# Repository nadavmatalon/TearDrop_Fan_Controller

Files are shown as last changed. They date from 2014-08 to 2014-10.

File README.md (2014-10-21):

#TearDrop Fan Controller

##Table of Contents

* [Screenshots](#screenshots)
* [About the Project](#about-the-project)
* [About the Fan Controller](#about-the-fan-controller)
* [License](#license)

##Screenshots

<table>
	<tr>
		<td align="center" width=25% >
			<a href="https://raw.githubusercontent.com/nadavmatalon/TearDrop_Fan_Controller/master/images/TDFC_Arduino.jpg">
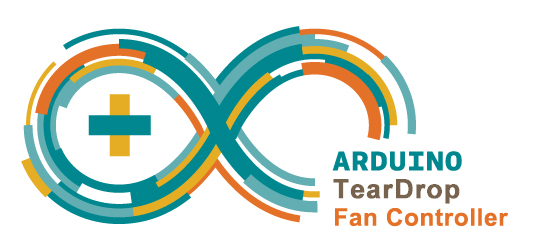
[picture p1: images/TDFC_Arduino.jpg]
				
			</a>
		</td>
		<td align="center" width=25% >
			<a href="https://raw.githubusercontent.com/nadavmatalon/TearDrop_Fan_Controller/master/images/TDFC_PCB.jpg">
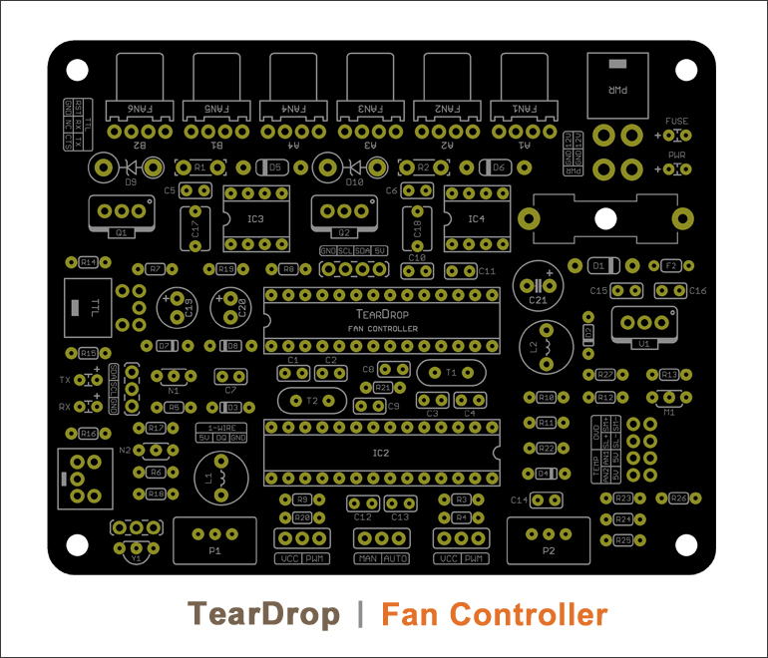
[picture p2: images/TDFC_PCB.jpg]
				
			</a>
		</td>
		<td align="center" width=25% >
			<a href="https://raw.githubusercontent.com/nadavmatalon/TearDrop_Fan_Controller/master/images/TearDrop_1.jpg">
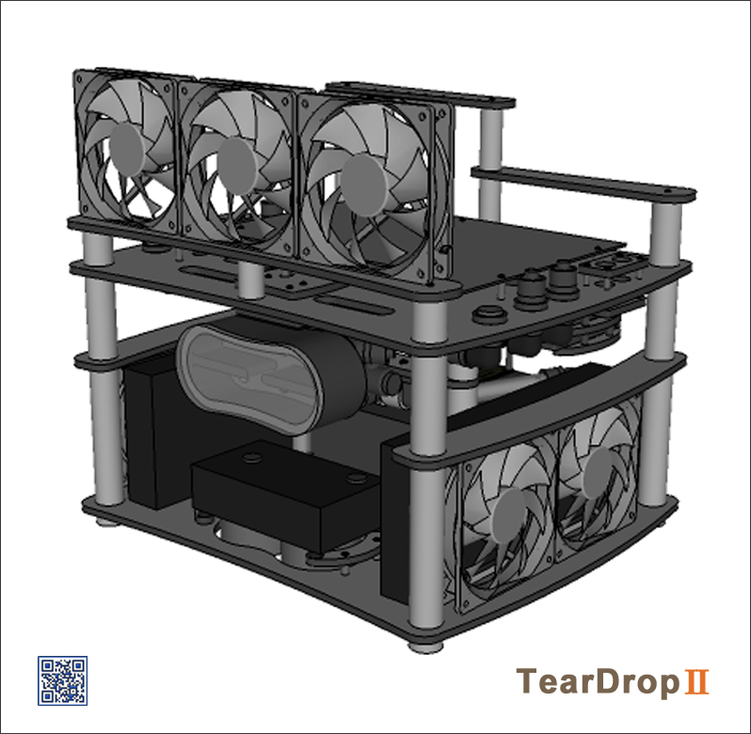
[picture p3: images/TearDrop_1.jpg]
				
			</a>
		</td>
		<td align="center" width=25% >
			<a href="https://raw.githubusercontent.com/nadavmatalon/TearDrop_Fan_Controller/master/images/TearDrop_2.jpg">
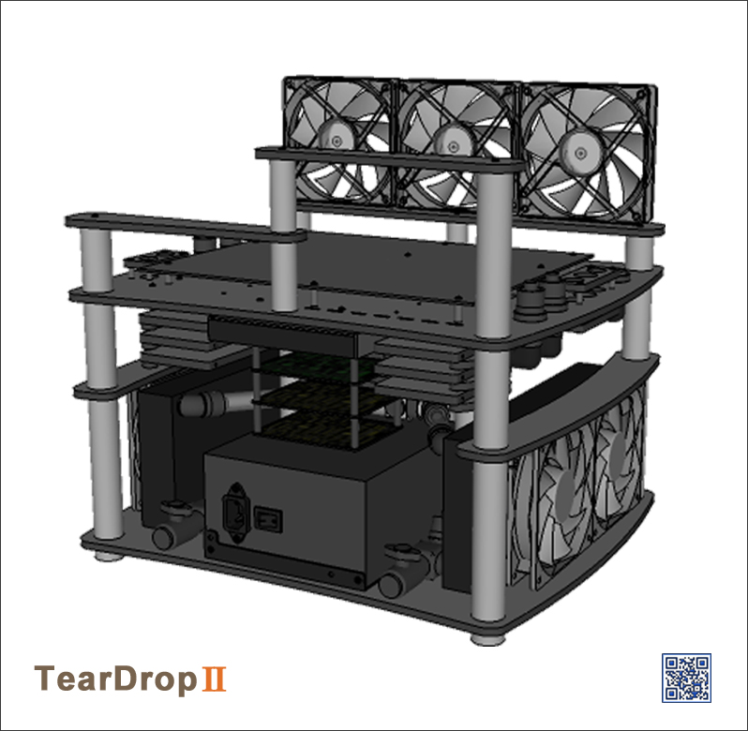
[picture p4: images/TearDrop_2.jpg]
				
			</a>
		</td>
	</tr>
</table>

##About the Project
 
__TearDrop__ is a custom, open-frame, water-cooled scratch build I’ve been 
working on as part of the SnowCrash initiative.

The __SnowCrash__ initiative aims at designing and building end-to-end customized 
personal computers, addressing unique functional requirements – from developing 
the software control applications, to hardware configuration and case modding. 
As part of the initiative's research phase, the TearDrop customized computer 
prototype has been developed.

The underlying motivation for this specifc project was to research, design, 
prototype and finally create everything that's needed for a fully-customized 
desktop computer.

In this context, I’ve learned to program micro-controllers, design, prototype 
and build electronic circuit boards, make CNC cutting templates, interface with 
various kinds of hardware, write front-end applications, and lots more.

This project also helped me to become proficient in multiple software tools, including: 
[Google Sketchup](http://www.sketchup.com/), 
[Arduino IDE](http://www.arduino.cc/), [Processing 2.0](http://processing.org/), 
[CadSoft Eagle](http://www.cadsoftusa.com/download-eagle/freeware/), 
and [Inkscape](http://www.inkscape.org/en/).
 
The __project-log__ of this build (which I haven't had time to update recently, but 
does include loads of cool pictures :-), can be found 
at [bit-tech](http://forums.bit-tech.net/showthread.php?t=234218).

##About the Fan Controller

This repo contains the custom Fan Controller I’ve designed and built 
to control __TearDrop__’s cooling fans.

This repo contains the following files:

* __arduino__

    The source code for the 2 x ATmega328P that run the Fan Controller 

    The files can can be directly accessed by clicking these links:

    * [Fan Controller: IC1](arduino/TearDrop_Fan_Controller_IC1/TearDrop_Fan_Controller_IC1.ino)

    * [Fan Controller: IC2](arduino/TearDrop_Fan_Controller_IC2/TearDrop_Fan_Controller_IC2.ino)

	The source code requires three supporting open-source [Arduino](http://www.arduino.cc/) libraries.

	For convenience, these libraries are inlcuded here in their own sub-folder.

	Credit goes to:

	[PinChangeInt](http://playground.arduino.cc/Main/PinChangeInt)

	[OneWire](https://github.com/ntruchsess/arduino-OneWire/tree/master)

	[WSWire](https://github.com/steamfire/WSWireLib)

* __eagle__

    This folder contains the complete hardware schematics & PCB design of the Fan Controller.

    __Please do not click on the files in this sub-folder as they are in foramts that 
    are incompatible with Github's hosting server__.

    However, the files can be downloaded and run as usual with [CadSoft](http://www.cadsoftusa.com/?language=en)'s 
    free version of [Eagle](http://www.cadsoftusa.com/download-eagle/freeware/).

* __parts__

	A speadsheet with all information about the parts used for building the Fan Controller.

	__The file in this sub-folder is also in a foramt that's incompatible with Github's hosting server__.

    However, it can be downloaded and run as usual with any spreadsheet editing software.

##  License

<p>Released under the <a href="http://www.opensource.org/licenses/MIT">MIT license</a>.</p>

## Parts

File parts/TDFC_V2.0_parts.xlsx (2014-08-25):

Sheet: Sheet1
TEARDROP
NAME | TYPE | VALUE / RATING | PACKAGE / DIMENSIONS | NUMBER | MANUFACTURER | MPN | SOURCE | DATASHEET | ACTUAL | ACTUAL | MINIMUM | ACTUAL | MINIMUM | MINIMUM | ACTUAL | MINIMUM | MINIMUM | MINIMUM
 |  |  | (mm) | OF |  |  |  | LEAD | LEAD | LEAD | HOLE | HOLE | ANNULAR RING | PAD | PAD | HOLE | PAD | PAD
 |  |  |  | UNITS |  |  |  | DIAMETER | DIAMETER | DIAMETER | DIAMETER | DIAMETER | SIZE | DIAMETER | DIAMETER | DIAMETER | DIAMETER | DIAMETER
 |  |  |  |  |  |  |  | (mm) | (wide side) | (narrow side) | (mm) | (mm) | (mm) | (mm) | (mm) | CHECK | CHECK (1) | CHECK (2)
PWR | 4P (2x2) POWER SOCKET (FEMALE) | 10A | KK, HORIZONTAL | 1 | MOLEX | MB-4PIN-SB | modDIY (MB-4PIN-SB) | ─ | 1.2 | 1.2 | 1.454 | 1.75 | 0.2 | 2.25 | 3.3 | 1.35 | 0.15 | 1.0
FAN 1-6 | 4P (1x4) POWER CONNECTOR (MALE, HORIZONTAL) | 10A | KK, HORIZONTAL | 6 | MOLEX |  |  | ─ | ─ | ─ | ─ | ─ | ─ | ─ | ─ | ─ | ─ | ─
USB-TTL | 6P (2x3) SOCKET (FEMALE) | HORIZONTAL, 2.54 |  | 1 | MOLEX | 90130-3206 | eBay (350819406809) |  |  |  | 0.254 |  | 0.2 | 0.5 | 1.7 | -0.4 | 1.7 | 1.2
USB-TTL | 6P (2x3) SOCKET (FEMALE) | VERTICAL, 2.54 |  | 1 | MOLEX | 90130-1206 | eBay (121194705280) |  |  |  | 0.254 |  | 0.2 | 0.5 | 1.7 | -0.4 | 1.7 | 1.2
USB-TTL | 6P (2x3) CONNECTOR (MALE) | ─ | ─ | 2 | MOLEX | 90142-0006 | eBay (111189947049) | ─ | ─ | ─ | ─ | ─ | ─ | ─ | ─ | ─ | ─ | ─
USB-TTL | CONNECTOR CRIMPS | ─ | ─ | 12 | MOLEX | 90119-2120 | eBay (111189965216) | ─ | ─ | ─ | ─ | ─ | ─ | ─ | ─ | ─ | ─ | ─
I/O | RIGHT-ANGLE MALE HEADERS | 2x4 | DUAL ROW, 2.54 | 1 | UNKOWN | UNKNOWN | eBay (321027689319) | ─ | 0.7 | 0.7 | 0.954 | 1.1 | 0.2 | 1.6 | 2.0 | 0.7 | 0.02 | 0.4
IC1, IC2 | ATMEGA328P | ─ | DIP-28 | 2 | ATMEL | ATMEGA328P | eBay(281158389853) | ─ | ─ | ─ | ─ | ─ | ─ | ─ | ─ | ─ | ─ | ─
(IC1, IC2) | DIL-28 SOCKET | ─ | 35.6x10, 2.54 | 2 | UNKNOWN | UNKNOWN | eBay(181062492231) | 0.5 | 0.5 | 0.5 | 0.754 | 0.7 | 0.2 | 1.2 | 1.8 | 0.3 | 0.54 | 0.6
IC2, IC3 | MIC4421 (MOFSET DRIVER) | 9A | DIP-8 | 2 | MICREL | MIC4421YN | Mouser (998-MIC4421YN) | ─ | ─ | ─ | ─ | ─ | ─ | ─ | ─ | ─ | ─ | ─
[IC2, IC3] | [MCP1406 (IMPROVEMENT OF TC4429)] | [6A] | [DIP-8] | [2] | MICROCHIP | MCP1406-E/P | Mouser (579-MCP1406-E/P) | ─ | ─ | ─ | ─ | ─ | ─ | ─ | ─ | ─ | ─ | ─
(IC2, IC3) | DIL-8 SOCKET | 3A | 10.1x10.2 | 2 | MILL-MAX | 110-44-308-41-001000 | Mouser (575-144308) | 0.5 | 0.5 | 0.5 | 0.754 | 0.7 | 0.2 | 1.2 | 1.8 | 0.3 | 0.54 | 0.6
 |  |  |  |  |  |  | Farnell (1351428)
[IC2, IC3] | [DIL-8 SOCKET] | [3A] | [10x10] | [2] | TE Connectivity / AMP | 808-AG11D-ES-LF | Mouser (571-4-1571552-3) | 0.5 | 0.5 | 0.5 | 0.754 | 0.7 | 0.2 | 1.2 | 1.8 | 0.3 | 0.54 | 0.6
Y1 | DS18B20 (DIGITAL TEMPERATURE SENSOR) | ─ | TO-92 | 1 | DALLAS | DS18B20 | eBay (301049284143) | 0.5 | 0.5 | 0.5 | 0.754 | 0.7 | 0.2 | 1.2 | 1.8 | 0.3 | 0.54 | 0.6
V1 | LM7805 (VOLTAGE REGULATOR) | 5V | TO-220 | 1 | FAIRCHILD | LM7805ACT | Mouser (512-LM7805ACT) | Narrow: 0.64 | 0.86 | 0.45 | 1.114 | 1.1 | 0.2 | 1.6 | 2.1 | 0.7 | 0.12 | 0.5
 |  |  |  |  |  |  |  | Wide: 1.52
[V1] | [LM7805 (VOLTAGE REGULATOR)] | [5V] | [TO-220] | [1] | ON SEMICONDUCTOR | MC33269T-5.0G | Mouser (863-MC33269T-5.0G) | Narrow: 0.64 | 0.86 | 0.45 | 1.114 | 1.2 | 0.2 | 1.7 | 2.1 | 0.8 | -0.06 | 0.4
 |  |  |  |  |  |  |  | Wide: 1.52
F1 | FAST-BLOW GLASS FUSE | 6.3A | 8x20MM | 1 | UKNOWN | UNKWNON | UNKNOWN | ─ | ─ | ─ | ─ | ─ | ─ | ─ | ─ | ─ | ─ | ─
(F1) | FUSE HOLDER | 10A / 250V | 22.5x9.6mm | 1 | Schurter | 0031.8211 | Mouser (693-0031.8201) | 1.3 | 1.2 | 0.46 | 1.454 | 1.45 | 0.2 | 1.95 | 3.3 | 1.05 | 0.69 | 1.3
F2 | PTC (RESETTABLE FUSE) | 0.5A / 60V | 6.8x1.9, 5.1 | 1 | BOURNS | MF-R050 | Mouser (652-MFR050) | 0.5 | 0.55 | 0.5 | 0.804 | 0.7 | 0.2 | 1.2 | 1.6 | 0.3 | 0.34 | 0.4
L1, L2 | INDUCTOR | 10uH / 4A7 | 8.7x12.3, 5.08 | 2 | Wurth Electronics | 7447452100 | Mouser (710-7447452100) | 0.7 | 0.65 | 0.7 | 0.904 | 0.9 | 0.2 | 1.4 | 2.1 | 0.5 | 0.48 | 0.7
C1, C2, C3, C4 | CAPACITOR (MLCC) | 22pF / 50V | 3.8x2, 2.6 | 4 | AVX | SR155A220JAR | Mouser (581-SR155A220JAR) | 0.5 | 0.5 | 0.5 | 0.754 | 0.7 | 0.2 | 1.2 | 1.7 | 0.3 | 0.44 | 0.5
C5 - C15 | CAPACITOR (MLCC) | 100nF / 100V | 4.3x2.9, 2.6 | 11 | NOT KNOWN | NOT KNOWN | eBay (290933035294) | 0.5 | 0.5 | 0.5 | 0.754 | 0.7 | 0.2 | 1.2 | 1.7 | 0.3 | 0.44 | 0.5
[C5 - C15] | [CAPACITOR (MLCC)] | [100nF / 25V] | [4x2.5, 3] | [11] | [TDK] | [FK18X7R1E104K] | [Mouser (810-FK18X7R1E104K)] | 0.5 | 0.5 | 0.5 | 0.754 | 0.7 | 0.2 | 1.2 | 1.8 | 0.3 | 0.54 | 0.6
C16 | CAPACITOR (MLCC) | 470nF / 25V | 4x2.5, 3 | 1 | TDK | FK18X7R1E474K | Mouser (810-FK18X7R1E474K) | 0.5 | 0.55 | 0.55 | 0.804 | 0.7 | 0.2 | 1.2 | 1.7 | 0.3 | 0.44 | 0.5
C17, C18 | WIMA CAPACITOR (5%) | 2.2uF / 50V | 5x7.2, 5.2 | 2 | WIMA | MKS2B042201F00JSSD | Mouser (505-MKS22.2/50/5) | 0.5 | 0.5 | 0.5 | 0.754 | 0.7 | 0.2 | 1.2 | 1.8 | 0.3 | 0.54 | 0.6
[C17, C18] | [WIMA CAPACITOR (10%)] | [2.2uF / 50V] | [5x7.2, 5] | [2] | [WIMA] | [MKS2B042201F00KSSD] | [Mouser (505-MKS22.2/50/10 )] |  |  |  | 0.254 |  |  | 0.1 |  | -0.4 | 0 | -0.5
[C17, C18] | [WIMA CAPACITOR (10%)] | [4.7uF / 50V] | [7.2x7.2, 5] | [2] | [WIMA] | [MKS2B044701K00KSSD] | [Mouser (505-MKS2-4.7/50/10)] |  |  |  | 0.254 |  |  | 0.1 |  | -0.4 | 0 | -0.5
[C17, C18] | [WIMA CAPACITOR (5%)] | [1uF / 63V] | [5x7.2, 5] | [2] | WIMA | [MKS2C041001F00JS] | [Mouser (505-MKS21.0/63/5)] |  |  |  | 0.254 |  |  | 0.1 |  | -0.4 | 0 | -0.5
[C17, C18] | [WIMA CAPACITOR (5%)] | [1uF / 63V] | [5x7.2, 5] | [2] | [WIMA] | [MKS2-1/63/5T] | [Mouser (505-MKS21/63/5T)] |  |  |  | 0.254 |  |  | 0.1 |  | -0.4 | 0 | -0.5
C19, C20 | CAPACITOR (ELECTROLYTIC) | 100uF / 50V | 8x12.2, 5 | 1 | PANASONIC | EEU-FR1H101B | Mouser (667-EEU-FR1H101B) | 0.6 | 0.6 | 0.6 | 0.854 | 0.9 | 0.2 | 1.4 | 2.1 | 0.5 | 0.48 | 0.7
C21 | CAPACITOR (ELECTROLITIC) | 470uF / 35V | 8.3x21.6, 3.5 | 1 | PANASONIC | EEU-FR1V471L | Mouser 667-EEU-FR1V471L | 0.6 | 0.6 | 0.6 | 0.854 | 0.9 | 0.2 | 1.4 | 2.1 | 0.5 | 0.48 | 0.7
Q1, Q2 | IRF5210 (P-CHANNEL MOSFET) | 30V / 50A | TO-220 | 2 | INTERNATIONAL RECIFIER | IRF5210PBF | Mouser (942-IRF5210PBF) | Narrow: 0.64 | 0.86 | 0.45 | 1.114 | 1.1 | 0.2 | 1.6 | 2.1 | 0.7 | 0.12 | 0.5
 |  |  |  |  |  |  |  | Wide: 1.52
(Q1, Q2, V1) | MOSFET / VOLTAGE REGULATOR HEATSINK (TO-220) | 32C/W | 6.35x13.3 | 3 | AAVID THERMALLOY | 577002B00000G | Mouser (532-577002B00) | ─ | ─ | ─ | ─ | ─ | ─ | ─ | ─ | ─ | ─ | ─
N1, N2 | ZVN2106A (N-CHANNEL MOSFET) | 0.2A / 60V | TO-92 | 2 | FAIRCHILD | ZVN2106A | Mouser (522-ZVN2106A) | 0.5 | 0.5 | 0.5 | 0.754 | 0.7 | 0.2 | 1.2 | 1.8 | 0.3 | 0.54 | 0.6
M1 | ZVP2106A (P-CHANNEL MOSFET) | 0.2A / 60V | 2.3x4.6 | 1 | DIODES INC | ZVP2106A | Mouser (522-ZVP2106A) | 0.5 | 0.5 | 0.5 | 0.754 | 0.7 | 0.2 | 1.2 | 1.8 | 0.3 | 0.54 | 0.6
D1 | 1N4007 (POWER DIODE) | 1000V / 1A | DO-41 (5x2.6) | 1 | FAIRCHILD SEMICONDUCTOR | 1N4007 | Farnell (1467514) | 0.87 | 0.8 | 0.8 | 1.054 | 0.9 | 0.2 | 1.4 | 2.2 | 0.5 | 0.58 | 0.8
D2 - D4 | 1N4148 (SIGNAL DIODE) | 100V / 200mA | DO-35 (3.2x1.6) | 3 | FAIRCHILD SEMICONDUCTORS | 1N4148 | Mouser (512-1N4148) | 0.56 | 0.5 | 0.5 | 0.754 | 0.7 | 0.2 | 1.2 | 1.8 | 0.3 | 0.54 | 0.6
D5, D6 | UF4004 (PROTECTION DIODE) | 40V / 30A | DO-41 (5x2.6) | 2 | VISHAY | UF4004-E3/54 | Mouser (625-UF4004-E3) | 0.8 | 0.8 | 0.8 | 1.054 | 0.9 | 0.2 | 1.4 | 2.2 | 0.5 | 0.58 | 0.8
D7, D8 | BZX79-B/C5V1 (ZENER DIODE) | 5V1 / 0.5W | DO-35 (3.6x1.6) | 2 | VISHAY | BZX55B5V1-TAP | Mouser (78-BZX55B5V1-TAP) | 0.5 | 0.5 | 0.5 | 0.754 | 0.7 | 0.2 | 1.2 | 1.8 | 0.3 | 0.54 | 0.6
D9, D10 | ICTE12 (TVS DIODE) | 12V / 1.5KW / UD | 9x5.2 | 2 | VISHAY | ICTE12-E3/51 | Mouser (625-ICTE12-E3/51) | 1.1 | 1.1 | 1.1 | 1.354 | 1.25 | 0.2 | 1.75 | 2.6 | 0.85 | 0.35 | 0.9
T1, T2 | CRYSTAL | 16Mhz | 10.8x4.4 | 2 | ABRACON | ABL-16.000MHZ-B2 | Mouser (815-ABL-16-B2) | 0.5 | 0.45 | 0.45 | 0.704 | 0.7 | 0.2 | 1.2 | 1.8 | 0.3 | 0.54 | 0.6
P1, P2 | POTENTIOMETER (SINGL TURN) | 10K | 12.7x7.6 | 2 | VISHAY SPECTROL | 249FGJSPXB25103KA | Farnell (9609342) | 0.5 | 0.5 | 0.4 | 0.754 | 0.7 | 0.2 | 1.2 | 1.8 | 0.3 | 0.54 | 0.6
(P1, P2) | POTENTIOMETER KNOB | ─ | 9.4x14 (Inner: 6mm) | 2 | UNKNOWN | UNKNOWN | eBay (310496284128) | ─ | ─ | ─ | ─ | ─ | ─ | ─ | ─ | ─ | ─ | ─
R1, R2 | RESISTOR | 100R / 15W | TO-126 (8.1x2.8) | 3 | CADDOCK | MP915-100-1% | Farnell (1612032) | 0.86 | 0.8 | 0.6 | 1.054 | 1.1 | 0.2 | 1.6 | 2.3 | 0.7 | 0.32 | 0.7
R3, R4 | RESISTOR | 470R / 0.5W | 3.15x1.6 | 2 | VISHAY | SFR16S0004700JA500 | Farnell (9476059) | 0.5 | 0.46 | 0.46 | 0.714 | 0.7 | 0.2 | 1.2 | 1.8 | 0.3 | 0.54 | 0.6
R5, R6 | RESISTOR | 1K / 0.5W | 3.15x1.6 | 4 | VISHAY | SFR16S0001001JA500 | Farnell (9475729) | 0.5 | 0.46 | 0.46 | 0.714 | 0.7 | 0.2 | 1.2 | 1.8 | 0.3 | 0.54 | 0.6
R7 - R13 | RESISTOR | 4K7 / 0.5W | 3.15x1.6 | 7 | VISHAY | SFR16S0004701JA500 | Farnell (9476083) | 0.5 | 0.46 | 0.46 | 0.714 | 0.7 | 0.2 | 1.2 | 1.8 | 0.3 | 0.54 | 0.6
R14 - R26 | RESISTOR | 10K / 0.5W | 3.15x1.6 | 13 | VISHAY | SFR16S0001002JA500 | Farnell (9475575) | 0.5 | 0.46 | 0.46 | 0.714 | 0.7 | 0.2 | 1.2 | 1.8 | 0.3 | 0.54 | 0.6
R27 | RESISTOR | 270K / 0.5W | 3.15x1.6 | 2 | VISHAY | SFR16S0002703JA500 | Farnell (9475842) | 0.5 | 0.46 | 0.46 | 0.714 | 0.7 | 0.2 | 1.2 | 1.8 | 0.3 | 0.54 | 0.6
PWR LED | LED (GREEN, 1.8mm) | ─ | 2.4x3.4, 2.6 | 1 | KINGBRIGHT | L-2060GD | eBay (251351814776) | 0.5 | 0.5 | 0.5 | 0.754 | 0.7 | 0.2 | 1.2 | 1.7 | 0.3 | 0.44 | 0.5
FUSE LED | LED (RED, 1.8mm) | ─ | 2.4x3.4, 2.6 | 1 | KINGBRIGHT | L-2060GD | eBay (251351814776) | 0.5 | 0.5 | 0.5 | 0.754 | 0.7 | 0.2 | 1.2 | 1.7 | 0.3 | 0.44 | 0.5
E3 | LED (AMBER, 1.8mm) | ─ | 2.4x3.2, 2.54 | 1 | KINGBRIGHT | L-2060ED | eBay (251351814776) | 0.5 | 0.5 | 0.5 | 0.754 | 0.7 | 0.2 | 1.2 | 1.7 | 0.3 | 0.44 | 0.5
E4 | LED (YELLOW, 1.8mm) | ─ | 2.4x3.2, 2.54 | 1 | KINGBRIGHT | L-2060YD | eBay (251351814776) | 0.5 | 0.5 | 0.5 | 0.754 | 0.7 | 0.2 | 1.2 | 1.7 | 0.3 | 0.44 | 0.5
S1 - S3 | SLIDING SWITCH | 400mA (G) / 100mA | 9x3.45 | 3 | ALCO | SSA12G | Mouser 506-SSA12G | (HOLE: 1.1) | 0.65 | 0.45 | 0.904 | 0.9 | 0.2 | 1.4 | 2.0 | 0.5 | 0.38 | 0.6
 |  |  |  |  |  |  | ebay (150964856124)
 |  |  |  |  |  |  | Farnell (2352003)

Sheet: Sheet2
ACTUAL | NUMBER | NUMBER | ACTUAL
HOLE | OF | OF | PAD
DIAMETER | HOLES | HOLES | DIAMETER
(mm) | CATEGORY | TOTAL | (mm)
0.8 | 12 | 91 | 1.6
0.9 | 4 | 38 | 2
1.1 | 4 | 46 | 2.1
1.2 | 2 | 15 | 2.0/2.3
1.75 | 3 | 12 | 3.3/3.4
3.2 | 1 | 4 | ─
 | TOTAL | 206

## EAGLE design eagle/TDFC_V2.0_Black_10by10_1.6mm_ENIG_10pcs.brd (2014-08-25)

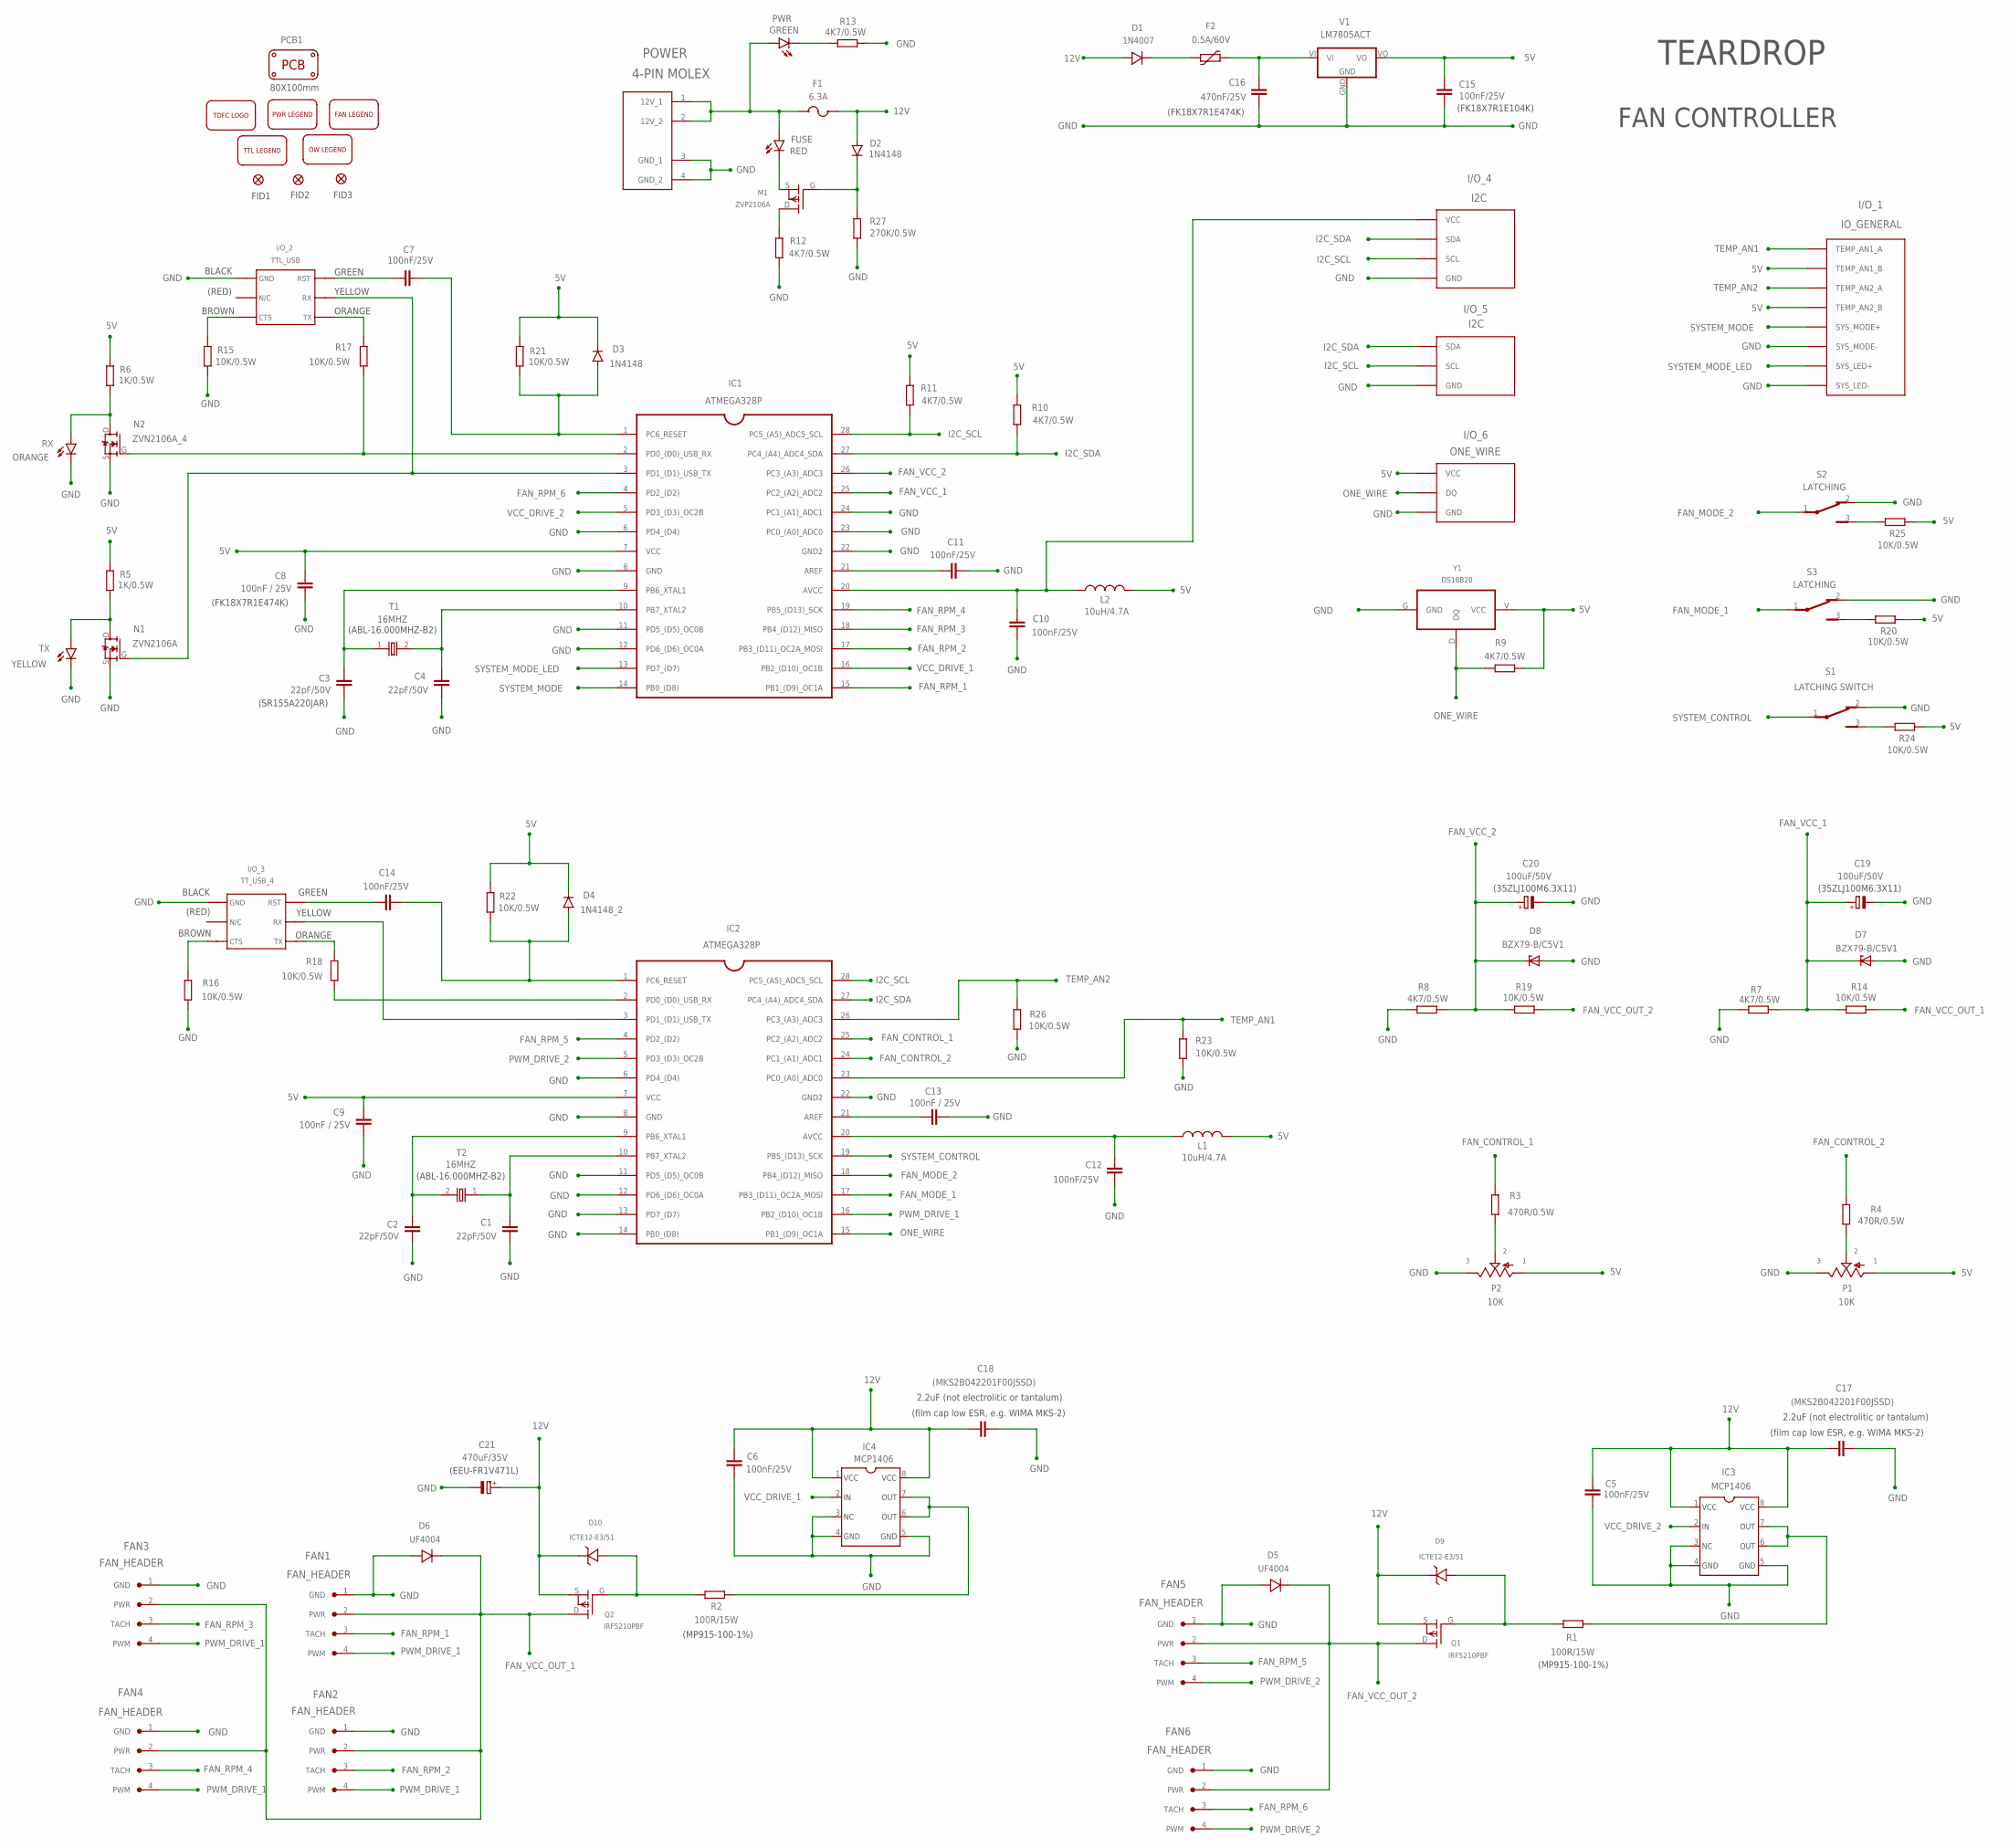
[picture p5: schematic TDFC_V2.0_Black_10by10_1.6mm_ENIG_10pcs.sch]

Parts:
C1, C2: 22pF/50V; MLCC_CERAMIC_9
C3, C4: 22pF/50V; MLCC_CERAMIC_11
C5, C6: 100nF/25V; MLCC_CERAMIC_5
C7: 100nF/25V; MLCC_CERAMIC_7
C8, C9: 100nF / 25V; MLCC_CERAMIC_5
C10: 100nF/25V; MLCC_CERAMIC
C11: 100nF/25V; MLCC_CERAMIC_17
C12: 100nF/25V; MLCC_CERAMIC_6
C13: 100nF / 25V; MLCC_CERAMIC_6
C14: 100nF/25V; MLCC_CERAMIC_14
C15: 100nF/25V; MLCC_CERAMIC_16
C16: 470nF/25V; MLCC_CERAMIC_15
C17, C18: (MKS2B042201F00JSSD); WIMA_CAPACITOR_2
C19, C20: 100uF/50V; CAPACITOR_6.3_RIGHT
C21: 470uF/35V; ELECTROLYTIC_CAPACITOR_RIGHT
D1: 1N4007; UF4004
D2, D3: 1N4148
D4: 1N4148_2
D5, D6: UF4004; UF4004_2
D7: BZX79-B/C5V1; DO34_2
D8: BZX79-B/C5V1; DO34Z7
D9, D10: ICTE12-E3/51; TVS_DIODE_5
F1: 6.3A; FUSE_GLASS
F2: 0.5A/60V; PTC
FAN1, FAN2, FAN3, FAN4, FAN5, FAN6: FAN_HEADER; 4PIN_FAN_HEADER
FID1, FID2, FID3: FIDUCIAL1X2; FIDUCIAL-1X2
FUSE: RED; LED_1.8_LEFT
I/O_1: IO_GENERAL; IO_GENERAL_7
I/O_2: TTL_USB; TTL_USB_5
I/O_3: TT_USB_4
I/O_4: I2C; 4_PIN_HEADER_VERTICAL_2
I/O_5: I2C; 3_PIN_VERTICAL_4
I/O_6: ONE_WIRE; 3_PIN_VERTICAL
IC1: ATMEGA328P
IC2: ATMEGA328P; ATMEGA328P_2
IC3, IC4: MCP1406; TC4420
L1, L2: 10uH/4.7A; INDUCTOR
M1: ZVP2106A
N1: ZVN2106A
N2: ZVN2106A_4
P1, P2: 10K; POTENTIMETER_SQUARE
PCB1: 80X100mm; DP10080_V1
POWER: 4-PIN MOLEX; MOLEX_4PIN_2
PWR: GREEN; LED_1.8_LEFT
Q1, Q2: IRF5210PBF; IRF5210
R1, R2: 100R/15W; V234/12
R3, R4: 470R/0.5W; 0204/5
R5, R6: 1K/0.5W; 0204/5
R7, R8, R9, R10, R11, R12, R13: 4K7/0.5W; 0204/5
R14, R15, R16, R17, R18, R19, R20, R21, R22, R23, R24, R25, R26: 10K/0.5W; 0204/5
R27: 270K/0.5W; 0204/5
RX: ORANGE; LED_1.8_LEFT_2
S1: LATCHING SWITCH; SLIDING_SWITCH_4
S2, S3: LATCHING; SLIDING_SWITCH_5
T1, T2: 16MHZ; CRYSTAL_16MHZ
TX: YELLOW; LED_1.8_LEFT_2
U$1: TDFC_LOGO
U$2: MOLEX_4PIN_LEGEND_2
U$3: FAN_HEADER_LEGEND
U$4: TTL_USB_6
U$5: 3_PIN_VERTICAL_LEGEND
V1: LM7805ACT; LM7805
Y1: DS18B20

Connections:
1: C10.1, I/O_4.VCC, IC1.20 (AVCC), L2.1
5V: C8.1, C9.1, C15.2, D3.C, D4.C, I/O_1.TEMP_AN1_B, I/O_1.TEMP_AN2_B, I/O_6.VCC, IC1.7 (VCC), IC2.7 (VCC), L1.2, L2.2, P1.1 (A), P2.1 (A), R5.2, R6.2, R9.2, R10.1, R11.1, R20.1, R21.2, R22.2, R24.2, R25.2, V1.VO, Y1.V (VCC)
12V: C5.2, C6.2, C17.1, C18.1, C21.+, D1.A, D2.A, D9.C, D10.C, F1.2, IC3.1, IC3.8, IC4.1, IC4.8, Q1.S, Q2.S
FAN_CONTROL_1: IC2.25 (PC2_(A2)_ADC2), R3.1
FAN_CONTROL_2: IC2.24 (PC1_(A1)_ADC1), R4.1
FAN_MODE_1: IC2.17 (PB3_(D11)_OC2A_MOSI), S3.1
FAN_MODE_2: IC2.18 (PB4_(D12)_MISO), S2.1
FAN_RPM_1: FAN1.3 (TACH), IC1.15 (PB1_(D9)_OC1A)
FAN_RPM_2: FAN2.3 (TACH), IC1.17 (PB3_(D11)_OC2A_MOSI)
FAN_RPM_3: FAN3.3 (TACH), IC1.18 (PB4_(D12)_MISO)
FAN_RPM_4: FAN4.3 (TACH), IC1.19 (PB5_(D13)_SCK)
FAN_RPM_5: FAN5.3 (TACH), IC2.4 (PD2_(D2))
FAN_RPM_6: FAN6.3 (TACH), IC1.4 (PD2_(D2))
FAN_VCC_1: C19.+, D7.C, IC1.25 (PC2_(A2)_ADC2), R7.1, R14.2
FAN_VCC_2: C20.+, D8.C, IC1.26 (PC3_(A3)_ADC3), R8.1, R19.2
FAN_VCC_OUT_1: D6.C, FAN1.2 (PWR), FAN2.2 (PWR), FAN3.2 (PWR), FAN4.2 (PWR), Q2.D, R14.1
FAN_VCC_OUT_2: D5.C, FAN5.2 (PWR), FAN6.2 (PWR), Q1.D, R19.1
GND: C1.2, C2.2, C3.2, C4.2, C5.1, C6.1, C8.2, C9.2, C10.2, C11.2, C12.2, C13.2, C15.1, C16.2, C17.2, C18.2, C19.-, C20.-, C21.-, D5.A, D6.A, D7.A, D8.A, FAN1.1 (GND), FAN2.1 (GND), FAN3.1 (GND), FAN4.1 (GND), FAN5.1 (GND), FAN6.1 (GND), I/O_1.SYSTEM_LED- (SYS_LED-), I/O_1.SYSTEM_MODE- (SYS_MODE-), I/O_2.GND, I/O_3.GND, I/O_4.GND, I/O_5.GND, I/O_6.GND, IC1.6 (PD4_(D4)), IC1.8 (GND), IC1.11 (PD5_(D5)_OC0B), IC1.12 (PD6_(D6)_OC0A), IC1.22 (GND2), IC1.23 (PC0_(A0)_ADC0), IC1.24 (PC1_(A1)_ADC1), IC2.6 (PD4_(D4)), IC2.8 (GND), IC2.11 (PD5_(D5)_OC0B), IC2.12 (PD6_(D6)_OC0A), IC2.13 (PD7_(D7)), IC2.14 (PB0_(D8)), IC2.22 (GND2), IC3.3, IC3.4, IC3.5, IC4.3, IC4.4, IC4.5, N1.S, N2.S, P1.3 (E), P2.3 (E), POWER.3 (GND_1), POWER.4 (GND_2), R7.2, R8.2, R12.1, R13.1, R15.1, R16.2, R23.2, R26.2, R27.2, RX.K (C), S1.2, S2.2, S3.2, TX.K (C), V1.GND, Y1.G (GND)
I2C_SCL: I/O_4.SCL, I/O_5.SCL, IC1.28 (PC5_(A5)_ADC5_SCL), IC2.28 (PC5_(A5)_ADC5_SCL), R11.2
I2C_SDA: I/O_4.SDA, I/O_5.SDA, IC1.27 (PC4_(A4)_ADC4_SDA), IC2.27 (PC4_(A4)_ADC4_SDA), R10.2
unnamed: C14.1, I/O_3.RST
unnamed: D2.C, M1.G, R27.1
unnamed: C13.1, IC2.21 (AREF)
unnamed: F1.1, FUSE.A, POWER.1 (12V_1), POWER.2 (12V_2), PWR.A
unnamed: PWR.K (C), R13.2
unnamed: I/O_3.RX, IC2.3 (PD1_(D1)_USB_TX)
unnamed: IC3.6, IC3.7, R1.2
unnamed: D10.A, Q2.G, R2.1
unnamed: IC4.6, IC4.7, R2.2
unnamed: FUSE.K (C), M1.S
unnamed: I/O_3.TX, R18.1
unnamed: C11.1, IC1.21 (AREF)
unnamed: D9.A, Q1.G, R1.1
unnamed: I/O_3.CTS, R16.1
unnamed: D1.C, F2.1
unnamed: N1.D, R5.1, TX.A
unnamed: N2.D, R6.1, RX.A
unnamed: M1.D, R12.2
unnamed: R25.1, S2.3
unnamed: C12.1, IC2.20 (AVCC), L1.1
unnamed: R20.2, S3.3
unnamed: IC2.2 (PD0_(D0)_USB_RX), R18.2
unnamed: R24.1, S1.3
unnamed: P2.2 (S), R3.2
unnamed: C4.1, IC1.10 (PB7_XTAL2), T1.2
unnamed: C14.2, D4.A, IC2.1 (PC6_RESET), R22.1
unnamed: C3.1, IC1.9 (PB6_XTAL1), T1.1
unnamed: P1.2 (S), R4.2
unnamed: C2.1, IC2.9 (PB6_XTAL1), T2.2
unnamed: C1.1, IC2.10 (PB7_XTAL2), T2.1
ONE_WIRE: I/O_6.DQ, IC2.15 (PB1_(D9)_OC1A), R9.1, Y1.D (DQ)
POST_FUSE: C16.1, F2.2, V1.VI
PWM_DRIVE_1: FAN1.4 (PWM), FAN2.4 (PWM), FAN3.4 (PWM), FAN4.4 (PWM), IC2.16 (PB2_(D10)_OC1B)
PWM_DRIVE_2: FAN5.4 (PWM), FAN6.4 (PWM), IC2.5 (PD3_(D3)_OC2B)
RESET: C7.1, D3.A, IC1.1 (PC6_RESET), R21.1
SYSTEM_CONTROL: IC2.19 (PB5_(D13)_SCK), S1.1
SYSTEM_MODE: I/O_1.SYSTEM_MODE+ (SYS_MODE+), IC1.14 (PB0_(D8))
SYSTEM_MODE_LED: I/O_1.SYSTEM_LED+ (SYS_LED+), IC1.13 (PD7_(D7))
TEMP_AN1: I/O_1.TEMP_AN1_A, IC2.23 (PC0_(A0)_ADC0), R23.1
TEMP_AN2: I/O_1.TEMP_AN2_A, IC2.26 (PC3_(A3)_ADC3), R26.1
USB_CTS: I/O_2.CTS, R15.2
USB_RESET_2: C7.2, I/O_2.RST
USB_RX: IC1.2 (PD0_(D0)_USB_RX), N2.G, R17.2
USB_RX_2: I/O_2.TX, R17.1
USB_TX: I/O_2.RX, IC1.3 (PD1_(D1)_USB_TX), N1.G
VCC_DRIVE_1: IC1.16 (PB2_(D10)_OC1B), IC4.2
VCC_DRIVE_2: IC1.5 (PD3_(D3)_OC2B), IC3.2

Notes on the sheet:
FID1
FID2
FID3
(film cap low ESR, e.g. WIMA MKS-2)
TEARDROP
GREEN
YELLOW
ORANGE
BROWN
BLACK
(RED)
2.2uF (not electrolitic or tantalum)
(FK18X7R1E104K)
(FK18X7R1E474K)
(SR155A220JAR)
(EEU-FR1V471L)
(35ZLJ100M6.3X11)
(MP915-100-1%)
FAN CONTROLLER
(ABL-16.000MHZ-B2)

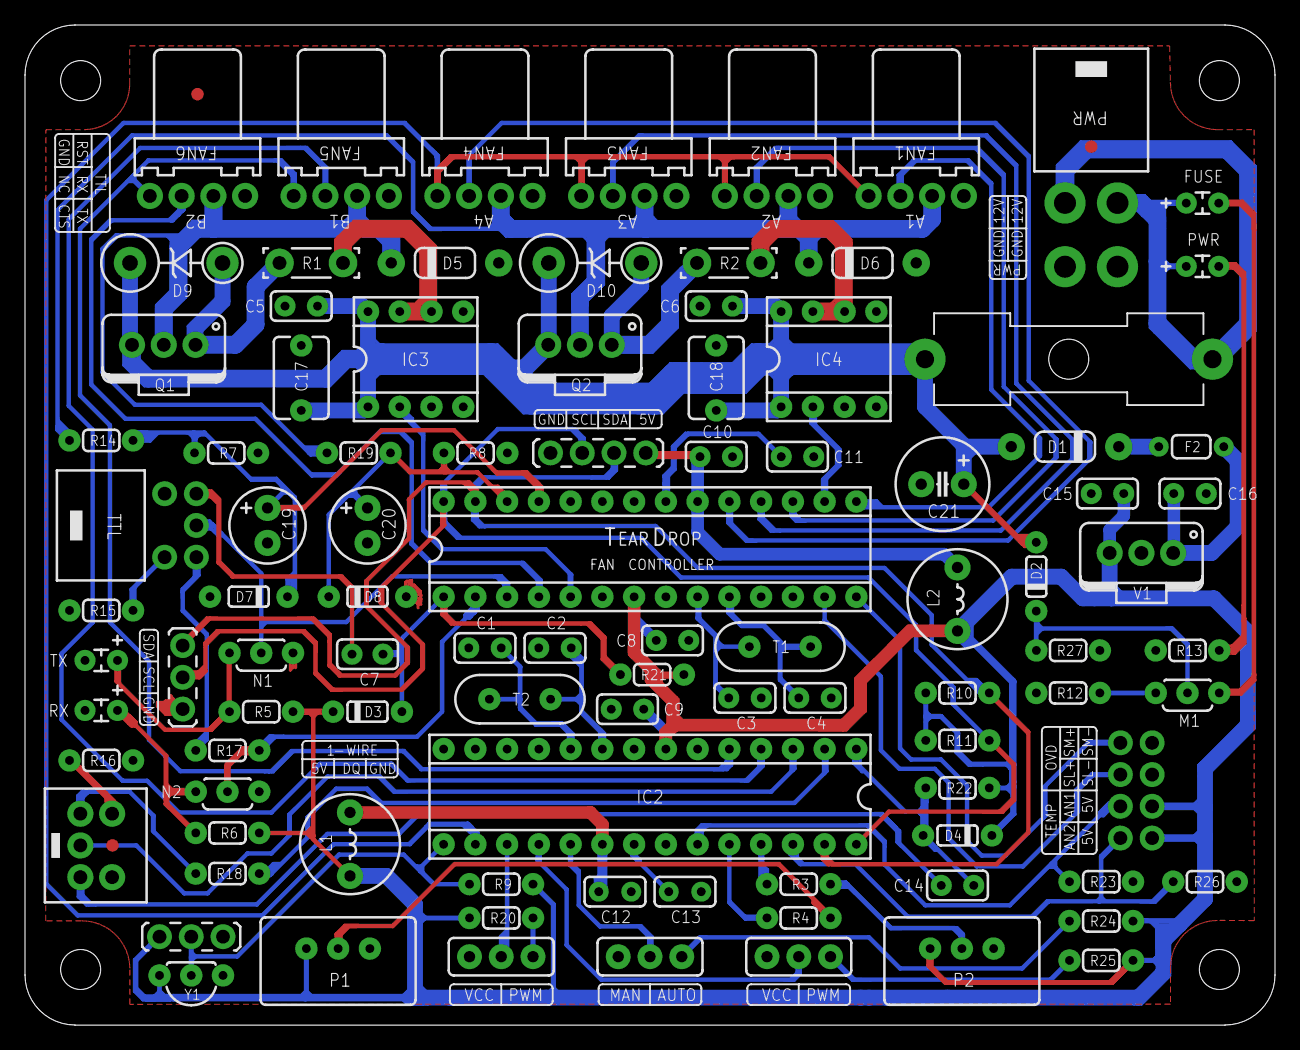
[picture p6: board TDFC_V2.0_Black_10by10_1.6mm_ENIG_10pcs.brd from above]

Board: 2 copper layers, 100.0 x 80.0 mm, 106 parts (0 on the bottom side), 67 nets.

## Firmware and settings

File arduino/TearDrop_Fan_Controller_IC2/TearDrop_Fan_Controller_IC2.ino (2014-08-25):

// TearDrop
// Fan Controller 
// IC 2
// Version 99.0
// ATmega328P
// Created by Nadav Matalon
// 24 August 2014

// (TDCR_IC2_FAN_99)


// FAN CONTROLLER: IC_2 (COM4)					

// PIN_D2  (PIN 4)  [PD2] - FAN_RPM_5
// PIN_D3  (PIN 5)  [PD3] - PWM_DRIVE_2 (F_5-6) 
// PIN_D4  (PIN 6)  [PD4] - GND		
// PIN_D5  (PIN 11) [PD5] - GND	
// PIN_D6  (PIN 12) [PD6] - GND	
// PIN_D7  (PIN 13) [PD7] - GND
// PIN_D8  (PIN 14) [PB0] - GND
// PIN_D9  (PIN 15) [PB1] - ONE_WIRE
// PIN_D10 (PIN 16) [PB2] - PWM_DRIVE_1 (F_1-4)
// PIN_D11 (PIN 17) [PB3] - FAN_MODE_1 (VCC_1/PWM_1)
// PIN_D12 (PIN 18) [PB4] - FAN_MODE_2 (VCC_2/PWM_2)
// PIN_D13 (PIN 19) [PB5] - SYSTEM_CONTROL_2 (MAN/AUTO)
// PIN_A0  (PIN 23) [PC0] - TEMP_AN1
// PIN_A1  (PIN 24) [PC1] - FAN_CONTROL_2
// PIN_A2  (PIN 25) [PC2] - FAN_CONTROL_1
// PIN_A3  (PIN 26) [PC3] - TEMP_AN2


// http://playground.arduino.cc/Main/PinChangeInt
// http://code.google.com/p/arduino-pinchangeint/
#include <PinChangeInt.h>

// http://playground.arduino.cc/Learning/OneWire
// https://github.com/ntruchsess/arduino-OneWire/tree/master
#include <OneWire.h>

// https://github.com/steamfire/WSWireLib
#include <WSWire.h>


const boolean DEBUG_MODE = false;		// DEBUG_MODE
// const boolean DEBUG_MODE = true;		// DEBUG_MODE

// const boolean PRINT_FIRST_ROW = false;	// DEBUG_MODE
const boolean PRINT_FIRST_ROW = true;		// DEBUG_MODE

const boolean PRINT_SECOND_ROW = false;		// DEBUG_MODE
// const boolean PRINT_SECOND_ROW = true;	// DEBUG_MODE


const byte PIN_D2 = 2;				// FAN_RPM_5	
const byte PIN_D3 = 3;				// PWM_DRIVE_2 (F_5-6) 
const byte PIN_D4 = 4;				// GND
const byte PIN_D5 = 5;				// GND
const byte PIN_D6 = 6;				// GND
const byte PIN_D7 = 7;				// GND
const byte PIN_D8 = 8;				// GND
const byte PIN_D9 = 9;				// ONE_WIRE
const byte PIN_D10 = 10;			// PWM_DRIVE_1 (F_1-4)
const byte PIN_D11 = 11;			// FAN_MODE_1 (VCC_1/PWM_1)
const byte PIN_D12 = 12;			// FAN_MODE_2 (VCC_2/PWM_2)
const byte PIN_D13 = 13;			// SYSTEM_CONTROL_2 (MAN/AUTO)
const byte PIN_A0 = A0;				// TEMP_AN1
const byte PIN_A1 = A1;				// FAN_CONTROL_2
const byte PIN_A2 = A2;				// FAN_CONTROL_1
const byte PIN_A3 = A3;				// TEMP_AN2

const byte ADC_A0 = 0;				// TEMP_AN1				// ADC input channel PIN_A0
const byte ADC_A1 = 1;				// FAN_CONTROL_2 (RAW_POT_2)		// ADC input channel PIN_A1
const byte ADC_A2 = 2;				// FAN_CONTROL_1 (RAW_POT_1)		// ADC input channel PIN_A2
const byte ADC_A3 = 3;				// TEMP_AN2				// ADC input channel PIN_A3
const byte ADC_A4 = 4;									// ADC input channel PIN_A4
const byte ADC_A5 = 5;									// ADC input channel PIN_A5
const byte ADC_TEMP = 8;			// M2_TEMP_IC				// ADC input channel IC_TEMP
const byte ADC_VCC = 14;			// M2_VCC_IC				// ADC input channel IC_VCC
const byte ADC_GND = 15;								// ADC input channel IC_GND

const float TEMP_OFFSET_A0 = 1.00;							// TEMP_AN1 - calibration function: higher OFFSET precentage => lower temperature readings
const float TEMP_OFFSET_A3 = 1.00;							// TEMP_AN2 - calibration function: higher OFFSET precentage => lower temperature readings

const unsigned int TEMP_RESISTOR_A0 = 10000;	// TEMP_AN1_RESISTOR			// TEMP_AN1 - resistor value on PIN_A0 (in Ohms)
const unsigned int TEMP_RESISTOR_A3 = 10000;	// TEMP_AN2_RESISTOR			// TEMP_AN2 - resistor value on PIN_A3 (in Ohms)

volatile unsigned long ovf1 = 0;		// TIMER1_OVERFLOW			// stores M2_TIMER1 overflow count
volatile unsigned long ovf2 = 0;		// TIMER2_OVERFLOW			// stores M2_TIMER2 overflow count

volatile unsigned long currentBurp_D2 = 0;						// FAN_RPM_5 - stores rpm count for ISR on PIN_D2

OneWire wireBus(PIN_D9);  						        	// sets up One-Wire bus on PIN_D9

const byte MAX_OW_DEVICES = 3;           						// determines maximum number of One-Wire devices on bus
const byte OW_DEVICE_1 = 0;								// One-Wire device 1 location in device address arrey
const byte OW_DEVICE_2 = 1;								// One-Wire device 2 location in device address arrey
const byte OW_DEVICE_3 = 2;								// One-Wire device 3 location in device address arrey

const byte MAX_I2C_TEMP_DEVICES = 2;             					// sets maximum number of digital temperature sensors on I2C bus
const byte I2C_DEVICE_1 = 0;								// I2C_device_1 location in I2C_address arrey
const byte I2C_DEVICE_2 = 1;								// I2C_device_2 location in I2C_address arrey

const byte M2_ADDRESS = 40;			// FAN_CONTROLLER_IC2			// M2 I2C device address

const byte M1_ADDRESS = 50;			// FAN_CONTROLLER_IC1			// M1 I2C device address

// const byte PC_ADDRESS = 60;			// PC_I2C_ADDRESS			// PC I2C device address

const byte M2_DATA_IN_COUNT = 8; 							// number of bytes recieved (max: 32 bytes)
const byte M2_DATA_OUT_COUNT = 30;

const byte M2_PACKAGE_1 = 241;
const byte M2_PACKAGE_2 = 242;
const byte M2_PACKAGE_3 = 243;

unsigned int freq_PWM_1 = 0;			// FREQ_PWM_1				// stores M2 TIMER1 frequency reading
unsigned int freq_PWM_2 = 0;			// FREQ_PWM_2				// stores M2 TIMER2 frequency reading

unsigned int M2_duty_cycle_1 = 638;		// M2_DUTY_CYCLE_1 (PWM_1)
unsigned int M2_duty_cycle_2 = 78;		// M2_DUTY_CYCLE_2 (PWM_2)

boolean system_control_2 = true;		// SYSTEM_CONTROL_2 (MAN/AUTO)		// SYSTEM_CONTROL_2 (0 => MAN / 1 => AUTO)

boolean fan_mode_1 = true;			// FAN_MODE_1 (VCC_1/PWM_1)		// FAN_MODE_1 (0 => VCC_1; 1 => PWM_1)

boolean fan_mode_2 = true;			// FAN_MODE_2 (VCC_2/PWM_2)		// FAN_MODE_2 (0 => VCC_2; 1 => PWM_2)

unsigned int fan_control_1 = 980;		// FAN_CONTROL_1 (RAW_POT_1)		// FAN_CONTROL_1 - raw pot reading for CHANNEL1
unsigned int fan_control_2 = 980;		// FAN_CONTROL_2 (RAW_POT_2)		// FAN_CONTROL_2 - raw pot reading for CHANNEL2

unsigned int real_pot_1 = 0;			// DEBUG_MODE
unsigned int real_pot_2 = 0;			// DEBUG_MODE

unsigned int fan_rpm_5 = 0;			// FAN_RPM_5				// FAN_RPM_5 - stores rpm reading on ATMEGA328P_2

unsigned int temp_AN1 = 0;			// TEMP_AN1				// stores TEMP_AN1 raw data
unsigned int temp_AN2 = 0;			// TEMP_AN2				// stores TEMP_AN2 raw data

unsigned int top_temp_AN = 550;			// TEMP_AN_TOP

byte wire_address [MAX_OW_DEVICES] [8] = {0};           				// sets up array of arrays for storing 8-byte address of each One-Wire device
byte total_OW_devices = 0;    	 							// stores current number of devices discovered on M2 One-Wire bus
boolean temp_OW_multiple = false;
unsigned int temp_OW_1 = 0;			// TEMP_OW_1				// stores temperature reading of OW_Device_1
unsigned int temp_OW_2 = 0;			// TEMP_OW_2				// stores temperature reading of OW_Device_2
unsigned int temp_OW_3 = 0;			// TEMP_OW_3				// stores temperature reading of OW_Device_3

byte I2C_address[MAX_I2C_TEMP_DEVICES] = {0};						// stores indivitual address of each I2C digital temperator sensor
byte total_I2C_devices = 0;            	                				// stores total number of digital temperature sensors discovered on I2C bus
boolean temp_I2C_present = false;
unsigned int temp_I2C_1 = 0;			// TEMP_I2C_1				// stores current temperature reading of I2C_device_1
unsigned int temp_I2C_2 = 0;			// TEMP_I2C_2				// stores current temperature reading of I2C_device_2

unsigned int vcc_IC = 0;			// VCC_IC				// stores M2_VCC_IC (in mV)
unsigned int temp_IC = 0;			// TEMP_IC				// stores M2_TEMP_IC in °C (multiplied by 10)
unsigned int ram_IC = 0;			// RAM_IC				// stores M2_RAM_IC

boolean serial_open = false;								// stores state of serial port

const unsigned long LONG_UPDATE_INTERVAL = 1555556;  					// stores long time interval (in uS) for data updates
const float LONG_UPDATE_DIVISOR = 1.555556;        	       				// stores long update divisor (in Sec) for data updates
unsigned long long_update_tick = 0;							// stores current time reference for long update loop
unsigned long long_update_tock = 0;							// stores previous time reference for long update loop

const unsigned long SHORT_UPDATE_INTERVAL = 333334;  					// stores short time interval (in uS) for data updates
unsigned long short_update_tick = 0;							// stores current time reference for short update loop
unsigned long short_update_tock = 0;							// stores previous time reference for short update loop

const unsigned long PACKAGE_2_INTERVAL = 600000;  						// stores short time interval (in uS) for data updates
unsigned long package_2_tick = 0;								// stores current time reference for short update loop
unsigned long package_2_tock = 0;								// stores previous time reference for short update loop

const unsigned long PACKAGE_3_INTERVAL = 900000;  						// stores short time interval (in uS) for data updates
unsigned long package_3_tick = 0;								// stores current time reference for short update loop
unsigned long package_3_tock = 0;								// stores previous time reference for short update loop


void setup() {

	DDRD &= ~(1 << DDD2); PORTD |= (1 << PORTD2);	// FAN_RPM_5 (PIN_D2)		// FAN_RPM_5 - pinMode(PIN_D2, INPUT_PULLUP)
	DDRD |= (1 << DDD3); 				// M2_TIMER2 (PIN_D3)		// PWM_DRIVE_2 (M2_TIMER2) - pinMode(PIN_D3, OUTPUT)
	DDRD &= ~(1 << DDD4);  								// GND - pinMode(PIN_D4, INPUT)
	DDRD &= ~(1 << DDD5);  								// GND - pinMode(PIN_D5, INPUT)
	DDRD &= ~(1 << DDD6);  								// GND - pinMode(PIN_D6, INPUT)
	DDRD &= ~(1 << DDD7);  								// GND - pinMode(PIN_D7, INPUT)
	DDRB &= ~(1 << DDB0);  								// GND - pinMode(PIN_D8, INPUT)
	DDRB |= (1 << DDB2); 				// M2_TIMER1 (PIN_D10)		// PWM_DRIVE_1 (M2_TIMER1) - pinMode(PIN_D10, OUTPUT)
	DDRB &= ~(1 << DDB3); 				// FAN_MODE_1 (PIN_D11)		// FAN_MODE_1 (VCC_1/PWM_1) - pinMode(PIN_D11, INPUT)
	DDRB &= ~(1 << DDB4); 				// FAN_MODE_2 (PIN_D12)		// FAN_MODE_2 (VCC_2/PWM_2) - pinMode(PIN_D12, INPUT)
	DDRB &= ~(1 << DDB5); 				// SYSTEM_CONTROL_2 (PIN_D13)	// SYSTEM_CONTROL_2 (MAN/AUTO) - pinMode(PIN_D13, INPUT)
	DDRC &= ~(1 << DDC0);				// TEMP_AN1			// TEMP_AN1 - pinMode(PIN_A0, INPUT)
	DDRC &= ~(1 << DDC1);				// FAN_CONTROL_2 (RAW_POT)	// FAN_CONTROL_2 - pinMode(PIN_A1, INPUT)
	DDRC &= ~(1 << DDC2);				// FAN_CONTROL_1 (RAW_POT)	// FAN_CONTROL_1 - pinMode(PIN_A2, INPUT)
	DDRC &= ~(1 << DDC3);				// TEMP_AN2			// TEMP_AN2 - pinMode(PIN_A3, INPUT)

// read_ADC() SETUP //

	ADMUX = 0; 									// resets entire ADMUX register to zero (ADC OFF, auto-trigger disabled)
	ADMUX |= (1 << REFS0);								// configures AVCC as ADC voltage reference
	ADMUX |= ADC_GND;								// sets ADC Mux input channel to GND							
        ADCSRA = 0;									// resets entire ADCSRA register to zero
	ADCSRA |= (1 << ADPS2) | (1 << ADPS1) | (1 << ADPS0);				// sets ADC with prescaler 128 (16MHz / 128 = 125KHz)
//	ADCSRA |= (1 << ADPS2) | (1 << ADPS1);						// sets ADC with prescaler 64 (16MHz / 64 = 250KHz)
//	ADCSRA |= (1 << ADPS2) | (1 << ADPS0);						// sets ADC with prescaler 32 (16MHz / 32 = 500KHz)
	ADCSRA |= (1 << ADEN) | (1 << ADSC);						// turns on ADC & preforms initial conversion

// M2_TIMER1 SETUP //

	cli();										// disables global interrupts
		TCCR1A = 0;								// resets entire Timer1 "Control Register A" to zero
											// (normal operation: OC1A & OC1B disconnected)
		TCCR1B = 0;								// resets entire Timer1 "Control Register B" to zero 
											// (Timer1 is OFF)										
		TIMSK1 |= (1 << TOIE1); 						// enables Timer1 "compare interrupt mask register A"
		TCCR1A |= (1 << COM1B1) | (1 << WGM11) | (1 << WGM10);			// set up Timer1 in FAST PWM mode (together with TCCR1B settings below)
											// (Timer1 prescaler = 1)
		TCCR1B |= (1 << WGM13) | (1 << WGM12);					// clears OC1B on Compare Match mode (OC1A as "TOP" & OC1B as "BOTTOM")
		OCR1A = 639;								// sets Timer1 "TOP" to generate 25KHz frequency (16Mhz / 1 / 640)
											// (Timer1 OVF ISR invoked every 40uS)
		OCR1B = 638;								// sets initial duty cycle on PIN_D10 (OC1B) to maximum value ("TOP"-1)
		TCCR1B |= (1 << CS10);							// turn on Timer1 (with prescaler 1)

// M2_TIMER2 SETUP //

		TCCR2A = 0;								// resets entire Timer2 "Control Register A" to zero
											// (normal operation: OC2A & OC2B disconnected)
		TCCR2B = 0;								// resets entire Timer2 "Control Register B" to zero
											// (Timer2 is OFF)
		TIMSK2 |= (1 << TOIE2);							// enables Timer2 "compare interrupt mask register A"
		TCCR2A |= (1 << COM2B1) | (1 << WGM21) | (1 << WGM20);			// set ups Timer2 in FAST PWM mode (together with TCCR2B settings below)
		TCCR2B |= (1 << WGM22);							// clears OC2B on Compare Match mode (OC2A as "TOP" & OC2B as "BOTTOM")
		OCR2A = 79;								// sets Timer2 "TOP" to generate 25KHz frequency (16Mhz / 8 / 80 = 25KHz)
											// (Timer2 OVF ISR invoked every 40uS)
		OCR2B = 78;								// sets initial duty cycle on PIN_D3 (OC2B) to maximum value ("TOP"-1)
		TCCR2B |= (1 << CS21);							// turns on Timer2 with prescaler 8
	sei();										// enables global interrupts

	PCintPort::attachInterrupt(PIN_D2, burpCount_D2, FALLING);			// FAN_RPM_5 - attaches software interrupt on PIN_D2


	total_OW_devices = discover_OW_Devices();					// searches & stores total number of temperature sensors on One-Wire bus (max: 4 devices)

	if (total_OW_devices > 1) temp_OW_multiple = true;


	total_I2C_devices = discover_I2C_Temp();    					// searchs for new devices on I2C bus

	if (total_I2C_devices > 0) temp_I2C_present = true;

 
  	Wire.begin(M2_ADDRESS);                	        				// joins I2C bus

	TWBR = 12; 									// TWBR 12: 400KHz (max); 32: 200KHz; 72: 100KHz (default)


	if (DEBUG_MODE) {

		Serial.begin(115200);							// opens serial port & begins serial communication

		check_Serial();								// checks if serial port is open
	}

	while (micros() < 150000) {}							// delay to desyncronize M2 to M1 & M1 to PC updates
}


void loop() {

	short_update_tock = micros();							// current time reference for short update function (in uS)

	package_2_tock = short_update_tock;

	package_3_tock = short_update_tock;

	long_update_tock = micros();							// current time reference for long update function (in uS)


	if ((short_update_tock - short_update_tick) >= SHORT_UPDATE_INTERVAL) {		// update function preformed every 0.333334 secondS

		short_update_tick = short_update_tock;					// stores current time reference for next update

		system_control_2 = update_Switch(PIN_D13);	// MAN/AUTO

		fan_mode_1 = update_Switch(PIN_D11);		// VCC_1/PWM_1

		fan_mode_2 = update_Switch(PIN_D12);		// VCC_2/PWM_2

		if (!system_control_2) {

			fan_control_1 = update_Fan_Control(PIN_A2);	// FAN_CONTROL_1

			fan_control_2 = update_Fan_Control(PIN_A1);	// FAN_CONTROL_2
		}

		M1_Get_Duty_Data(M1_ADDRESS);			// GET_DUTY_CYCLE	// gets M2_TIMER1 & M2_TIMER2 duty cycle data from M1

		update_Duty_Cycle(PIN_D10);			// PWM_1 		// DUTY_CYCLE_1 (M2_TIMER1)

		update_Duty_Cycle(PIN_D3);			// PWM_2 		// DUTY_CYCLE_2 (M2_TIMER2)

		M2_Send_Data_M1(M2_PACKAGE_1); 
	}



	if ((package_2_tock - package_2_tick) >= PACKAGE_2_INTERVAL) {				// update function preformed every 1.555556 secondS

		package_2_tick = package_2_tock;						// stores current time reference for next update

		M2_Send_Data_M1(M2_PACKAGE_2); 
 	}

	if ((package_3_tock - package_3_tick) >= PACKAGE_3_INTERVAL) {				// update function preformed every 1.555556 secondS

		package_3_tick = package_3_tock;						// stores current time reference for next update

		M2_Send_Data_M1(M2_PACKAGE_3);  
 	}


	if ((long_update_tock - long_update_tick) >= LONG_UPDATE_INTERVAL) {		// update function preformed every 1.555556 secondS

		long_update_tick = long_update_tock;					// stores current time reference for next update

		freq_PWM_1 = update_Frequency(PIN_D10);		// FREQ_PWM_1		// calculates PWM frequency on PIN_D10

		freq_PWM_2 = update_Frequency(PIN_D3);		// FREQ_PWM_2		// calculates PWM frequency on PIN_D3

		temp_OW_1 = read_OW_Temp(OW_DEVICE_1);		// TEMP_OW_1

		vcc_IC = update_Vcc_IC();			// VCC_IC		// reads VCC_IC

		temp_AN1 = update_Temp_AN(PIN_A0);		// TEMP_AN1

		fan_rpm_5 = update_Fan_RPM(PIN_D2);		// FAN_RPM_5		// updates rpm reading on PIN_D2

		temp_AN2 = update_Temp_AN(PIN_A3);		// TEMP_AN2

		top_temp_AN = update_Top_Temp_AN();		// TEMP_AN_TOP

		if (temp_OW_multiple) update_OW_Temp();		// TEMP_OW		// updates reading of One-Wire temperature sensors if available

		temp_IC = update_Temp_IC();			// TEMP_IC		// reads temp_IC

		if (temp_I2C_present) update_I2C_Temp();	// TEMP_I2C		// updates reading of I2C temeprature sensors if available

		ram_IC = update_Ram_IC();			// RAM_IC		// reads ram_IC

		if ((DEBUG_MODE) && (serial_open)) print_Long_Update();			// preforms debugging serial print function

		if ((DEBUG_MODE) && (!serial_open)) check_Serial();			// checks if serial port in open for communication
	}
}


ISR(TIMER1_OVF_vect) {									// Timer1 ISR (pwm frequency counter)
  	ovf1++;										// counts the number of Timer1 overflows
}


ISR(TIMER2_OVF_vect) {									// Timer2 ISR (pwm frequency counter)
  	ovf2++;										// counts the number of Timer2 overflows
}


void burpCount_D2() {									// ISR for interrupt triggers on PIN_D2
  	currentBurp_D2++;
}


boolean update_Switch (const byte switch_pin) {

	static boolean switch_result;

	switch (switch_pin) {

		case (PIN_D11):					// VCC_1/PWM_1

			switch_result = bitRead(PINB, 3);							// FAN_MODE_1 (0 => VCC_1; 1 => PWM_1) - digitalRead(PIN_D11)
		
			break;

		case (PIN_D12):					// VCC_2/PWM_2

			switch_result = bitRead(PINB, 4);							// FAN_MODE_2 (0 => VCC_2; 1 => PWM_2) - digitalRead(PIN_D12)

			break;

		case (PIN_D13):					// MAN/AUTO

			switch_result = bitRead(PINB, 5);							// SYSTEM_CONTROL_2 (0 => MAN; 1 => AUTO) - digitalRead(PIN_D13)

			break;
	}

	return switch_result;
}


unsigned int update_Fan_Control (const byte control_pin) {

	static unsigned int current_pot;
	static unsigned int previous_pot_1;					// stores previous reading on selected pin (multiplied by 10)
	static unsigned int previous_pot_2;					// stores previous reading on selected pin (multiplied by 10)
	static unsigned int delta_pot;						// stores delta between current_pot_data_1 & previous_pot_data_1 (multiplied by 10)

	switch (control_pin) {							

		case (PIN_A2): 					// FAN_CONTROL_1

			current_pot = read_ADC(ADC_A2);
			if (DEBUG_MODE) real_pot_1 = current_pot;
			if (current_pot < 40) current_pot = 40;
			if (current_pot > 880) current_pot = 880;
			delta_pot = abs(current_pot - previous_pot_1);
			if ((delta_pot >= 25) || (current_pot < 65) || (current_pot > 850) || (previous_pot_1 == 0)) previous_pot_1 = current_pot;
		        else current_pot = previous_pot_1;
			break;

		case (PIN_A1): 					// FAN_cONTROL_2

			current_pot = read_ADC(ADC_A1);
			if (DEBUG_MODE) real_pot_2 = current_pot;
			if (current_pot < 40) current_pot = 40;
			if (current_pot > 880) current_pot = 880;
			delta_pot = abs(current_pot - previous_pot_2);
			if ((delta_pot >= 25) || (current_pot < 65) || (current_pot > 850) || (previous_pot_2 == 0)) previous_pot_2 = current_pot;
		        else current_pot = previous_pot_2;
			break;
	}

	if (current_pot < 40) current_pot = 40;
	if (current_pot > 880) current_pot = 880;

	return current_pot;
}


unsigned int update_Fan_RPM (const byte fan_pin) {

	static unsigned int current_rpm;								// stores current rpm reading on selected pin
	static unsigned int previous_rpm;								// stores previous rpm reading on selected pin
	static unsigned int delta_rpm;									// stores delta rpm between previous & current readings

     	previous_rpm = fan_rpm_5;

	cli();												// disables global interrupts
		current_rpm = currentBurp_D2;								// obtains current rpm count from interrupt routine
		currentBurp_D2 = 0;									// resets rpm count on PIN_D9 to zero
	sei();												// enables global interrupts

	current_rpm = round((current_rpm * 30.0) / LONG_UPDATE_DIVISOR);				// calculates current rpm within the update time interval
	delta_rpm = abs(current_rpm - previous_rpm);							// calculates delta between previous & current rpm readings 
	if (current_rpm < 300) current_rpm = 0;
	if (current_rpm > 4000) current_rpm = previous_rpm;
	if (current_rpm > previous_rpm) current_rpm = round((current_rpm + previous_rpm) / 2.0);					// averages previous & current readings
	if (current_rpm < 300) current_rpm = 0;
	if ((delta_rpm < 15) && (current_rpm > 300)) current_rpm = previous_rpm;
	else previous_rpm = current_rpm;

	return current_rpm;
}


unsigned int update_Frequency (const byte freq_pin) {

	static unsigned int current_freq;			      					// stores total overflow count of selected timer
//	static volatile unsigned int current_freq;		      					// stores total overflow count of selected timer
	static unsigned int previous_freq_1;
	static unsigned int previous_freq_2;
	static unsigned int delta_freq;

	switch (freq_pin) {

		case (PIN_D10):						// FREQ_PWM_1

			cli();
				current_freq = ovf1; 							// stores number of M2_TIMER1 overflow
				ovf1 = 0; 								// resets M2_TIMER1 overflow counter to zero
			sei();

		 	current_freq = round(current_freq / LONG_UPDATE_DIVISOR);
//		 	current_freq = round(float(current_freq) / LONG_UPDATE_DIVISOR);

			delta_freq = abs(current_freq - previous_freq_1);

			if ((delta_freq >= 10) || (current_freq < 24500)) previous_freq_1 = current_freq;
			else current_freq = previous_freq_1;

			break;

		case (PIN_D3):						// FREQ_PWM_2

			cli();
				current_freq = ovf2; 							// stores number of M2_TIMER2 overflow
				ovf2 = 0; 								// resets M2_TIMER2 overflow counter to zero
			sei();

		 	current_freq = round(current_freq / LONG_UPDATE_DIVISOR);
//		 	current_freq = round(float(current_freq) / LONG_UPDATE_DIVISOR);

			delta_freq = abs(current_freq - previous_freq_2);

			if ((delta_freq >= 10) || (current_freq < 24500)) previous_freq_2 = current_freq;
			else current_freq = previous_freq_2;

			break;
	}
	return current_freq;
}
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

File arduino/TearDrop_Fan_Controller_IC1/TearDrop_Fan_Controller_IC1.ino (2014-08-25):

// TearDrop
// Fan Controller 
// IC 1
// Version 99.0 
// ATmega328P
// Created by Nadav Matalon
// 24 August 2014

// (TDCR_IC1_FAN_99)


// FAN CONTROLLER: IC_1	(COM6)					

// PIN_D2  (PIN 4)  [PD2] - FAN_RPM_6		
// PIN_D3  (PIN 5)  [PD3] - VCC_DRIVE_2 (F_5-6) 
// PIN_D4  (PIN 6)  [PD4] - GND			
// PIN_D5  (PIN 11) [PD5] - GND			
// PIN_D6  (PIN 12) [PD6] - GND			
// PIN_D7  (PIN 13) [PD7] - SYSTEM_CONTROL_LED	
// PIN_D8  (PIN 14) [PB0] - SYSTEM_CONTROL_1 (OVD_ON/OVD_OFF)
// PIN_D9  (PIN 15) [PB1] - FAN_RPM_1
// PIN_D10 (PIN 16) [PB2] - VCC_DRIVE_1 (F_1-4)
// PIN_D11 (PIN 17) [PB3] - FAN_RPM_2
// PIN_D12 (PIN 18) [PB4] - FAN_RPM_3
// PIN_D13 (PIN 19) [PB5] - FAN_RPM_4
// PIN_A0  (PIN 23) [PC0] - GND	
// PIN_A1  (PIN 24) [PC1] - GND
// PIN_A2  (PIN 25) [PC2] - FAN_VCC_1
// PIN_A3  (PIN 26) [PC3] - FAN_VCC_2


// http://playground.arduino.cc/Main/PinChangeInt
// http://code.google.com/p/arduino-pinchangeint/
#include <PinChangeInt.h>

// https://github.com/steamfire/WSWireLib
#include <WSWire.h>


const boolean DEBUG_MODE = false;		// DEBUG_MODE
// const boolean DEBUG_MODE = true;		// DEBUG_MODE

// const boolean PRINT_FIRST_ROW = false;	// DEBUG_MODE
const boolean PRINT_FIRST_ROW = true;		// DEBUG_MODE

// const boolean PRINT_SECOND_ROW = false;	// DEBUG_MODE
const boolean PRINT_SECOND_ROW = true;		// DEBUG_MODE

const boolean PRINT_THIRD_ROW = false;		// DEBUG_MODE
// const boolean PRINT_THIRD_ROW = true;	// DEBUG_MODE

const boolean PRINT_FOURTH_ROW = false;		// DEBUG_MODE
// const boolean PRINT_FOURTH_ROW = true;	// DEBUG_MODE


const byte PIN_D2 = 2;				// FAN_RPM_6	
const byte PIN_D3 = 3;				// VCC_DRIVE_2 (F_5-6) 
const byte PIN_D4 = 4;				// GND
const byte PIN_D5 = 5;				// GND
const byte PIN_D6 = 6;				// GND
const byte PIN_D7 = 7;				// SYSTEM_CONTROL_LED
const byte PIN_D8 = 8;				// SYSTEM_CONTROL_1 (OVD_ON/OVD_OFF)
const byte PIN_D9 = 9;				// FAN_RPM_1
const byte PIN_D10 = 10;			// VCC_DRIVE_1 (F_1-4)
const byte PIN_D11 = 11;			// FAN_RPM_2
const byte PIN_D12 = 12;			// FAN_RPM_3
const byte PIN_D13 = 13;			// FAN_RPM_4
const byte PIN_A0 = A0;				// GND
const byte PIN_A1 = A1;				// GND
const byte PIN_A2 = A2;				// FAN_VCC_1
const byte PIN_A3 = A3;				// FAN_VCC_2

const byte ADC_A0 = 0;										// ADC input channel PIN_A0
const byte ADC_A1 = 1;										// ADC input channel PIN_A1
const byte ADC_A2 = 2;				// FAN_VCC_1					// ADC input channel PIN_A2
const byte ADC_A3 = 3;				// FAN_VCC_2					// ADC input channel PIN_A3
const byte ADC_A4 = 4;										// ADC input channel PIN_A4
const byte ADC_A5 = 5;										// ADC input channel PIN_A5
const byte ADC_TEMP = 8;			// M1_TEMP_IC					// ADC input channel IC_TEMP
const byte ADC_VCC = 14;			// M1_VCC_IC					// ADC input channel IC_VCC
const byte ADC_GND = 15;									// ADC input channel IC_GND

// const byte M2_ADDRESS = 40;			// FAN_CONTROLLER_IC2				// M2 I2C device address

const byte M1_ADDRESS = 50;			// FAN_CONTROLLER_IC1				// M1 I2C device address
const byte M1_DATA_OUT_COUNT = 8; 								// number of bytes sent (max: 32 bytes)
const byte M1_DATA_IN_COUNT = 30; 								// number of bytes sent (max: 32 bytes)

const byte PC_ADDRESS = 60;			// PC_I2C_ADDRESS				// PC I2C device address
const byte PC_DATA_OUT_COUNT = 30;
const byte PC_PING = 100;
const byte PC_PING_COUNT = 1;

const byte M2_PACKAGE_1 = 241;
const byte M2_PACKAGE_2 = 242;
const byte M2_PACKAGE_3 = 243;

const byte PC_PACKAGE_1 = 245;
const byte PC_PACKAGE_2 = 246;
const byte PC_PACKAGE_3 = 247;
const byte PC_PACKAGE_4 = 248;

const unsigned int FC_SYSTEM_CONTROL_1 = 2001;	// SYSTEM_CONTROL_1 (OVD_OFF/OVD_ON)		// FC_SYSTEM_CONTROL_1 processing update command
const unsigned int FC_SYSTEM_CONTROL_2 = 2002;	// SYSTEM_CONTROL_2 (MAN/AUTO)			// FC_SYSTEM_CONTROL_2 processing update command
const unsigned int FC_FAN_VCC_1 = 2003;		// FAN_VCC_1					// FC_FAN_VCC_1 processing update command
const unsigned int FC_FAN_VCC_2 = 2004;		// FAN_VCC_2					// FC_FAN_VCC_2 processing update command
const unsigned int FC_VCC_ICF = 2005;		// VCC_ICF (BOTTOM)				// FC_VCC_IC processing update command
const unsigned int FC_FAN_MODE_1 = 2006;	// FAN_MODE_1 (VCC_1/PWM_1)			// FC_FAN_MODE_1 processing update command
const unsigned int FC_FAN_RPM_1 = 2007;		// FAN_RPM_1					// FC_FAN_RPM_1 processing update command
const unsigned int FC_FAN_RPM_2 = 2008;		// FAN_RPM_2					// FC_FAN_RPM_2 processing update command
const unsigned int FC_FAN_RPM_3 = 2009;		// FAN_RPM_3					// FC_FAN_RPM_3 processing update command
const unsigned int FC_FAN_RPM_4 = 2010;		// FAN_RPM_4					// FC_FAN_RPM_4 processing update command
const unsigned int FC_DUTY_CYCLE_PER_1 = 2011;	// DUTY_CYCLE_PER_1				// FC_DUTY_CYCLE_PER_1 processing update command
const unsigned int FC_FAN_MODE_2 = 2012;	// FAN_MODE_2 (VCC_2/PWM_2)			// FC_FAN_MODE_2 processing update command
const unsigned int FC_FAN_RPM_5 = 2013;		// FAN_RPM_5					// FC_FAN_RPM_5 processing update command
const unsigned int FC_FAN_RPM_6 = 2014;		// FAN_RPM_6					// FC_FAN_RPM_6 processing update command
const unsigned int FC_DUTY_CYCLE_PER_2 = 2015;	// DUTY_CYCLE_PER_2				// FC_DUTY_CYCLE_PER_2 processing update command
const unsigned int FC_TEMP_AN1 = 2016;		// TEMP_AN1					// FC_TEMP_AN3 processing update command
const unsigned int FC_TEMP_AN2 = 2017;		// TEMP_AN2					// FC_TEMP_AN4 processing update command
const unsigned int FC_TEMP_DGF = 2018;		// TEMP_DGF (TEMP_OW_1)				// FC_TEMP_DG processing update command
const unsigned int FC_TEMP_ICF = 2019;		// TEMP_ICF (TOP)				// FC_TEMP_IC processing update command
const unsigned int FC_FREQ_VCC_1 = 2020;	// FREQ_VCC_1					// FC_FREQ_VCC_1 processing update command
const unsigned int FC_FREQ_PWM_1 = 2021;	// FREQ_PWM_1					// FC_FREQ_PWM_1 processing update command
const unsigned int FC_FREQ_VCC_2 = 2022;	// FREQ_VCC_2					// FC_FREQ_VCC_2 processing update command
const unsigned int FC_FREQ_PWM_2 = 2023;	// FREQ_PWM_2					// FC_FREQ_PWM_2 processing update command
const unsigned int FC_RAM_ICF = 2024;		// RAM_ICF (BOTTOM)				// FC_RAM_ICF processing update command

const unsigned int FC_TEMP_OW_3 = 2025;		// TEMP_OW_3					// FC_TEMP_OW_3 processing update command
const unsigned int FC_TEMP_OW_4 = 2026;		// TEMP_OW_4					// FC_TEMP_OW_4 processing update command

const unsigned int FC_TEMP_I2C_3 = 2027;	// TEMP_I2C_3					// FC_TEMP_I2C_3 processing update command
const unsigned int FC_TEMP_I2C_4 = 2028;	// TEMP_I2C_4					// FC_TEMP_I2C_4 processing update command

const unsigned int FC_PLACE_HOLDER = 2029;	// PLACE_HOLDER					// FC_PLACE_HOLDER processing update command

volatile boolean M2_got_data = false;
volatile byte M2_data_in[M1_DATA_IN_COUNT] = {0};
volatile byte M2_data_out[M1_DATA_OUT_COUNT] = {0};

volatile unsigned long ovf1 = 0;		// TIMER1_OVERFLOW				// stores M1_TIMER1 overflow count
volatile unsigned long ovf2 = 0;		// TIMER2_OVERFLOW				// stores M1_TIMER2 overflow count
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

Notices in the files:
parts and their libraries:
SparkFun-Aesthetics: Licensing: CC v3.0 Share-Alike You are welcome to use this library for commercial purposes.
